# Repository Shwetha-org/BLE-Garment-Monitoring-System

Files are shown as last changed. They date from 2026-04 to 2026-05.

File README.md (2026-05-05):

# BLE Garment Monitoring System

## Overview

This project presents an end-to-end system for monitoring garment usage using a custom Bluetooth Low Energy (BLE) tag, edge processing, and a mobile application.

The system tracks garment states such as **worn**, **stored**, and **washed** by analyzing sensor data broadcast from a custom BLE-enabled garment tag.

---
## Custom BLE Garment Tag

<p align="center">
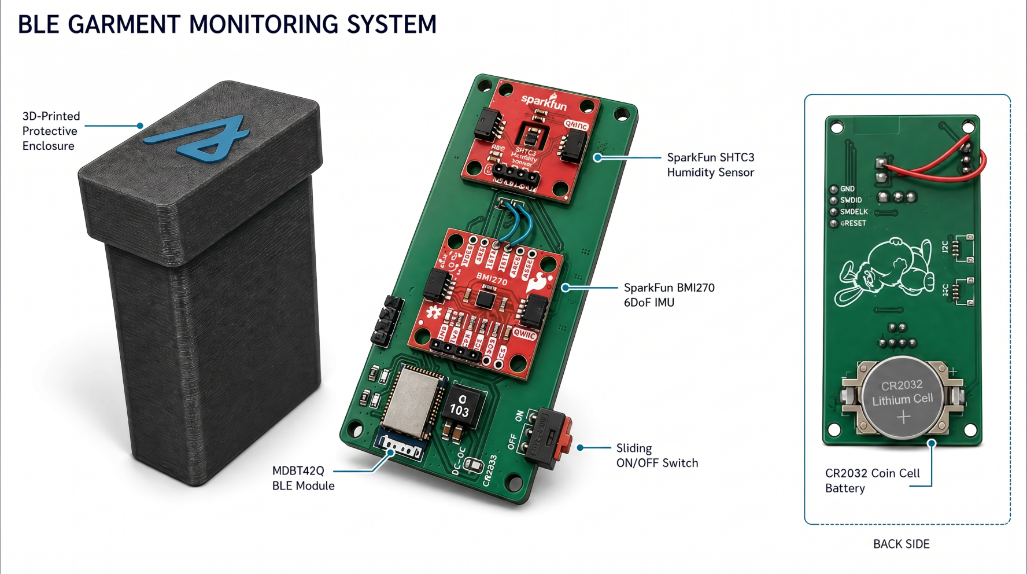
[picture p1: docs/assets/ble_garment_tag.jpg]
  
</p>

<p align="center">
  Custom BLE garment tag with integrated motion (BMI270) and humidity (SHTC3) sensors, powered by a CR2032 coin cell.
</p>

---

## System Architecture

The system consists of four main components:

### 1. Hardware (`hardware/garment_tag/`)

* Custom PCB design (KiCad)
* BLE module (nRF52832 – Raytac MDBT42Q)
* Sensors:

  * BMI270 (motion / acceleration)
  * SHTC3 (humidity and temperature)
* Assembly and manufacturing files

---

### 2. Firmware (`firmware/garment_tag/`)

* Zephyr-based firmware for the BLE tag
* Reads sensor data and encodes it into BLE advertisement payloads
* Broadcasts data continuously

---

### 3. Edge Node (`edge/`)

* Runs on Raspberry Pi
* Scans BLE advertisements using Python and Bleak
* Processes data using filtering and aggregation
* Classifies garment states (worn / stored / washed)
* Stores data in SQLite database
* Exposes REST API (`/summary`) using Flask

---

### 4. Android Application (`android_app/garment_tracker_app/`)

* Built with Kotlin and Jetpack Compose
* Connects to edge node API
* Displays:

  * Current garment state
  * Wear count
  * Wash count
* Includes privacy controls and live updates

---

## Data Flow

1. Sensors on the BLE tag collect motion, humidity, and temperature
2. Firmware encodes data into BLE advertisements
3. Raspberry Pi scans and processes the data
4. Classification pipeline determines garment state
5. Results are stored locally and exposed via API
6. Android app fetches and displays usage summaries

---

## BLE Payload Structure

The edge node expects manufacturer-specific data in the following format:

* Byte 0 → motion (0 or 1)
* Byte 1 → humidity (%)
* Byte 2 → temperature offset (temp + 40)

Manufacturer ID: `1027`

---

## Getting Started

### 1. Hardware

* Assemble the custom BLE tag
* Flash firmware onto the nRF52832

### 2. Edge Node

```bash
cd edge
pip install -r requirements.txt
python pipeline_final.py
```

### 3. Android App

* Open `android_app/garment_tracker_app/` in Android Studio
* Update Raspberry Pi IP in the code
* Run the application

---

## Requirements

* Raspberry Pi with Bluetooth
* Custom BLE garment tag
* Android device
* Python 3.x

---

## Notes

* The system operates on a local network
* The Android app requires the Raspberry Pi API to be running
* BLE payload structure must match firmware and edge logic

---

## Documentation

Detailed documentation is available in:

* `docs/architecture.md` – system design and component overview  
* `docs/setup_guide.md` – installation and setup instructions  
* `docs/User_Manual.pdf` – how to use the system (end-user guide)

---

## Project Scope

This project focuses on:

* Edge-based processing (no cloud dependency)
* Privacy-preserving garment tracking
* Lightweight BLE-based sensing

---

## License

This project is developed for academic purposes.

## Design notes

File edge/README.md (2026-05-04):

# Edge Node (Raspberry Pi)

## Overview

This component runs on the Raspberry Pi and is the core of the system.
It performs BLE scanning, signal processing, garment state classification, local data storage, and exposes a REST API for the Android application.

---

## Responsibilities

The edge node is responsible for:

* Scanning BLE advertisements from the garment tag
* Extracting sensor data (motion, humidity, temperature, gyro, RSSI)
* Applying filtering and aggregation using sliding windows
* Detecting garment states:

  * stored
  * worn
  * washed
* Storing processed data in a local SQLite database
* Exposing the latest state via a Flask API (`/summary`)

---

## Files

- `pipeline_final.py`  
  Main system used on the Raspberry Pi.  
  It scans BLE advertisements, processes sensor data, performs garment state classification, stores results in a SQLite database, and exposes a REST API.

- `scan_dk_beacon.py`  
  Debug script used with the nRF52 DK beacon.  
  It scans BLE advertisements, filters manufacturer-specific data from Nordic Semiconductor devices, and prints device ID, status, and RSSI to verify correct beacon transmission.

- `requirements.txt`  
  Dependency file for the edge node.  
  It lists the Python libraries required to run the BLE scanner, processing pipeline, and API server.

- `data/`  
  Runtime directory used by the edge node.  
  It stores the SQLite database (`garment_data.db`) that is automatically created and updated during system execution.

---

## Requirements

* Python 3.9+
* Raspberry Pi with Bluetooth enabled
* Linux environment (tested on Raspberry Pi OS)

---

## Installation

Install dependencies:

```bash
pip install -r requirements.txt
```

---

## Running the System

IMPORTANT: You must run the script from inside the `edge/` folder.

```bash
cd edge
python pipeline_final.py
```

---

## Output

### 1. SQLite Database

The system creates a database at:

```
edge/data/garment_data.db
```

This file is generated automatically at runtime and is not included in the repository.

---

### 2. Console Logs

Example output:

```
in-room | moving | state=worn | wears=2 | washes=1 | gyro_mag=4200.0 | rssi=-65 | rssi_stable=True | wash_candidate=False | wash_score=0.20
```

---

### 3. API Endpoint

The Flask server runs on:

```
http://<raspberry-pi-ip>:5000/summary
```

Example response:

```json
{
  "device_id": "0x0403",
  "state": "worn",
  "room_state": "in-room",
  "movement_state": "moving",
  "wears": 2,
  "washes": 1,
  "humidity": 45.2,
  "gyro_mag": 4100,
  "rssi": -65,
  "rssi_stable": true,
  "wash_score": 0.2
}
```

---

## State Detection Logic (Summary)

The system uses lightweight edge processing:

* Movement detection:
  Based on averaged motion values

* Room detection:
  Based on RSSI threshold

* Wash detection:
  Based on:

  * high gyro magnitude
  * stable RSSI
  * rolling wash score

* Wear detection:
  Based on sustained movement over a time window

---

## Important Notes

* The database path is relative to the current working directory
  → Always run the script from `edge/`

* The database file is created automatically
  → Do not manually add it to the repository

* BLE data is filtered to remove invalid samples before processing

---

## Debugging

To test BLE reception only:

```bash
python scan_dk_beacon.py
```

This prints raw beacon RSSI and ID values.

---

## Limitations

* Designed for a single garment device (`device_id = 0x0403`)
* Uses simple threshold-based classification
* Not optimized for multi-device environments

---

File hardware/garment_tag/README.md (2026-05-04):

# Garment Tag Hardware

## Overview

This folder contains the hardware design files for the custom BLE garment tag used in the garment monitoring system.

The garment tag is a custom-built embedded device that integrates a BLE module and sensors on a single PCB. It continuously broadcasts sensor data via BLE advertisements, which are received and processed by the Raspberry Pi edge node.

---

## Folder Structure

* `kicad/`
  Contains the KiCad schematic and PCB design files.

* `assembly/`
  Contains reference images of the assembled PCB.

* `manufacturing/`
  Contains Gerber files, drill files, and BOM used for PCB fabrication.

---

## Main Hardware Components

* Raytac MDBT42Q (nRF52832 BLE module used for BLE advertising)
* IMU sensor (used for motion and gyroscope data)
* Humidity sensor
* Coin cell battery (power supply)
* Custom PCB integrating all components into a wearable garment tag

The custom PCB integrates the BLE module and sensors into a single wearable device that continuously broadcasts environmental and motion data via BLE advertisements.

---

## KiCad Design Files

The PCB and schematic can be opened using KiCad:

```text
hardware/garment_tag/kicad/
```

Key files:

```text
ble beacon.kicad_pcb
ble beacon.kicad_sch
ble beacon.kicad_pro
```

---

## Manufacturing Files

Manufacturing files are located in:

```text
hardware/garment_tag/manufacturing/
```

These include:

* Copper layers
* Solder mask layers
* Silkscreen layers
* Drill files
* BOM (bill of materials) CSV

These files can be directly used for PCB fabrication.

---

## Assembly Reference

Assembly images are located in:

```text
hardware/garment_tag/assembly/
```

These show:

* Front of PCB
* Back of PCB
* Close-up component placement

They can be used as reference when assembling the board.

---

## Reproduction Steps

1. Open the KiCad project from `kicad/`.
2. Review the schematic and PCB layout.
3. Use the files in `manufacturing/` to fabricate the PCB.
4. Use the BOM to source components.
5. Assemble the PCB using the reference images in `assembly/`.
6. Flash firmware onto the BLE module using the nRF52 DK via SWD.
7. Power the board using a coin cell battery.
8. Verify that the device broadcasts BLE advertisement data.

---

## Notes

* The nRF52 DK is used only as a development and flashing tool.
* The custom garment tag PCB is the actual BLE device used in the system.
* The BLE advertisements from this device are processed by the edge node (`pipeline_final.py`).

---

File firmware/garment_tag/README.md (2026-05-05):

# BLE Tag Firmware

## Overview

This folder contains the firmware for the custom BLE garment tag.

The firmware runs on the nRF52832-based custom PCB and broadcasts sensor data using BLE manufacturer-specific advertisements. The Raspberry Pi edge node reads these advertisements and uses the values for garment state detection.

---

## Main Firmware File

src/customPCB_firmware.c

---

## Platform

- Zephyr RTOS  
- nRF52832 (Raytac MDBT42Q BLE module)  
- nRF52 DK used for flashing/debugging via SWD  

---

## Sensors Used

- BMI270 (IMU / accelerometer)  
- SHTC3 (humidity and temperature sensor)  

---

## Functionality

The firmware:

- initializes I2C communication  
- reads acceleration data from the BMI270  
- estimates motion based on acceleration changes  
- reads humidity and temperature from the SHTC3  
- encodes the sensor values into a BLE advertisement payload  
- broadcasts the payload periodically  

---

## BLE Advertisement Payload

The firmware encodes sensor data into manufacturer-specific data.

Expected structure:

- Byte 0 → motion flag (0 or 1)  
- Byte 1 → humidity (%)  
- Byte 2 → temperature offset (temp + 40)  

The edge node parses this payload using the same byte positions.

Manufacturer ID:

1027

---

## Flashing

1. Connect the custom PCB to the nRF52 DK using SWD  
2. Build the firmware using Zephyr  
3. Flash the firmware onto the BLE module  
4. Power the board using a coin cell battery  
5. Verify BLE advertisements using the edge node or debug scripts  

---

## Notes

- The firmware broadcasts BLE advertisements continuously  
- The payload format must match what is expected in `pipeline_final.py`  
- Incorrect payload structure will break state detection  
- The device may advertise under a custom name (e.g. MyBeacon)

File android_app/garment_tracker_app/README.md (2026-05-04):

# Android Application

## Overview

This Android application is the mobile user interface for the BLE Garment Monitoring System.

The app is built using Kotlin and Jetpack Compose. It connects to the Raspberry Pi edge node through a REST API and displays the latest garment usage summary.

---

## Main File

The main application logic is implemented in:

app/src/main/java/com/example/garmentlifecycletrackingapp/MainActivity.kt

This file contains:

- Jetpack Compose UI  
- Retrofit API connection  
- garment state display  
- wear and wash counters  
- connection status indicator  
- privacy settings dialog  

---

## Functionality

The app displays:

- current garment state  
- wear count  
- wash count  
- connection status  
- privacy settings  

The UI refreshes automatically every 2 seconds while data collection is enabled.

---

## API Connection

The app connects to the Raspberry Pi Flask API:

http://<raspberry-pi-ip>:5000/summary

In `MainActivity.kt`, the current base URL is set here:

.baseUrl("http://172.20.10.12:5000/")

When running the system on a different network, replace this IP address with the Raspberry Pi IP address.

---

## Expected API Response

The app expects a JSON response in this format:

{
  "device_id": "0x0403",
  "state": "worn",
  "wears": 2,
  "washes": 1
}

Only these fields are currently used by the Android app:

- device_id  
- state  
- wears  
- washes  

---

## Technologies Used

- Kotlin  
- Jetpack Compose  
- Material 3  
- Retrofit  
- Gson converter  
- SharedPreferences  

---

## How to Run

1. Open android_app/GarmentLifecycleTrackingApp/ in Android Studio  
2. Make sure the Raspberry Pi edge node is running  
3. Update the API base URL in MainActivity.kt  
4. Build and run the app on an Android device or emulator  

---

## Notes

- The Raspberry Pi and Android device must be on the same local network  
- The Flask API must be running before the app can display live data  
- If the app cannot connect to the API, it shows an offline/error state  
- Privacy settings are stored locally using SharedPreferences

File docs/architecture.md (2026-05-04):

# System Architecture

## Overview

The BLE Garment Monitoring System is an IoT-based system that monitors garment usage using a custom BLE garment tag, a Raspberry Pi edge node, local storage, and an Android application.

The system detects basic garment states:

* stored
* worn
* washed

---

## High-Level Architecture

```text
[Custom BLE Garment Tag]
          |
          | BLE advertisements
          v
[Raspberry Pi Edge Node]
          |
          | processing + classification
          v
[SQLite Database + Flask API]
          |
          | HTTP GET /summary
          v
[Android App]
```

---

## Components

### 1. Custom BLE Garment Tag

The garment tag is a custom PCB attached to a garment. It includes:

* Raytac MDBT42Q (nRF52832 BLE module)
* IMU sensor (motion + gyroscope)
* humidity sensor
* coin cell battery

The tag broadcasts sensor data using BLE advertisements.

Hardware files:

```text
hardware/garment_tag/
```

---

### 2. Raspberry Pi Edge Node

The Raspberry Pi acts as the edge-processing unit.

It is responsible for:

* scanning BLE advertisements
* extracting sensor data
* applying filtering and aggregation
* classifying garment state
* storing readings in SQLite
* exposing a REST API

Edge software:

```text
edge/
```

---

### 3. Local SQLite Database

The SQLite database stores processed BLE readings locally.

It is created at runtime and not included in the repository.

Expected location:

```text
edge/data/garment_data.db
```

---

### 4. Flask API

The edge node exposes:

```text
GET /summary
```

This endpoint returns the latest garment state and summary data.

---

### 5. Android Application

The Android app connects to the Raspberry Pi and displays garment state and usage.

API endpoint:

```text
http://<raspberry-pi-ip>:5000/summary
```

---

## Data Flow

1. The garment tag broadcasts sensor data via BLE.
2. The Raspberry Pi scans BLE advertisements.
3. Data is validated and filtered.
4. RSSI, motion, humidity, temperature, and gyro values are processed.
5. The system classifies the garment as stored, worn, or washed.
6. The result is stored in SQLite.
7. The latest summary is exposed via the Flask API.
8. The Android app fetches and displays the data.

---

## Design Decisions

### Edge Processing

Processing is performed locally on the Raspberry Pi.

Reasons:

* reduces data transmission
* keeps raw data local
* supports privacy
* enables offline operation

---

### SQLite Storage

SQLite is used because it is lightweight and suitable for local storage on the Raspberry Pi.

---

### Flask API

Flask provides a simple REST interface for communication with the Android application.

---

### BLE Advertisements

BLE advertisements are used instead of connections to allow low-power broadcasting without maintaining a connection.

---

## State Detection Summary

The system uses threshold-based logic and sliding windows:

* RSSI threshold → in-room vs out-of-room
* motion window → movement detection
* gyro magnitude → wash detection
* RSSI stability → distinguishes washing from movement
* wash score → confirms washing over time

---

## Current Limitations

* Supports a single garment tag
* Uses threshold-based classification (not ML-based)
* Requires tuning for different environments
* Database is local to the Raspberry Pi

---

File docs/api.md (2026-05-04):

# API

## Overview

The edge node exposes a REST API over HTTP.
The Android application uses this API to retrieve the latest garment state.

Base URL:

```text
http://<raspberry-pi-ip>:5000
```

---

## Endpoint

### GET /summary

Returns the latest processed garment data.

---

## Request

```http
GET /summary HTTP/1.1
Host: <raspberry-pi-ip>:5000
```

No parameters required.

---

## Response

```json
{
  "device_id": "0x0403",
  "state": "stored",
  "room_state": "in-room",
  "movement_state": "stationary",
  "wears": 0,
  "washes": 0,
  "humidity": 0,
  "gyro_mag": 0,
  "rssi": -65,
  "rssi_stable": true,
  "wash_score": 0
}
```

---

## Field Descriptions

* `device_id`
  Identifier of the BLE garment tag.

* `state`
  Current garment state: `stored`, `worn`, or `washed`.

* `room_state`
  Indicates whether the garment is detected as in-room or out-of-room based on RSSI.

* `movement_state`
  Indicates whether movement is detected (`moving` or `stationary`).

* `wears`
  Number of detected wear sessions.

* `washes`
  Number of detected wash events.

* `humidity`
  Averaged humidity value from sensor readings.

* `gyro_mag`
  Magnitude of gyroscope data used for motion analysis.

* `rssi`
  Received Signal Strength Indicator from BLE advertisement.

* `rssi_stable`
  Boolean indicating stability of RSSI values.

* `wash_score`
  Rolling score used to confirm wash detection.

---

## Usage Notes

* The API always returns the latest processed state.
* No authentication is required.
* The endpoint is intended for local network use.

---

## Error Handling

If the edge node is not running, the endpoint will not respond.

Ensure:

* `pipeline_final.py` is running
* Raspberry Pi is connected to the network
* correct IP address is used

---

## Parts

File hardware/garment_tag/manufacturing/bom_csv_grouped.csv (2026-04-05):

Reference | Qty | Value | DNP | Exclude from BOM | Exclude from Board | Footprint | Datasheet
C1,C2 | 2 | 10uF |  |  |  | Capacitor_SMD:C_0805_2012Metric
C3 | 1 | 1uF |  |  |  | Capacitor_SMD:C_0805_2012Metric
D1,D2 | 2 | LED |  |  |  | LED_SMD:LED_0603_1608Metric
J1 | 1 | Conn_01x03_Socket |  |  |  | Connector_PinHeader_2.54mm:PinHeader_1x03_P2.54mm_Vertical
J2 | 1 | bat |  |  |  | Battery:BatteryHolder_Keystone_1060_1x2032
J3,J8 | 2 | jst sh |  |  |  | Connector_JST:JST_SH_SM04B-SRSS-TB_1x04-1MP_P1.00mm_Horizontal
J4 | 1 | swd |  |  |  | Connector_PinHeader_2.54mm:PinHeader_1x04_P2.54mm_Vertical
J5,J6 | 2 | io |  |  |  | Connector_PinHeader_2.54mm:PinHeader_1x04_P2.54mm_Vertical
J7 | 1 | int |  |  |  | Connector_PinHeader_2.54mm:PinHeader_1x02_P2.54mm_Vertical
L2 | 1 | 10uH |  |  |  | Inductor_SMD:L_Coilcraft_XAL6030-XXX
R1,R2 | 2 | 2k2 |  |  |  | Resistor_SMD:R_0805_2012Metric
U1 | 1 | MDBT42Q-512K |  |  |  | RF_Module:Raytac_MDBT42Q | https://www.raytac.com/download/index.php?index_id=27

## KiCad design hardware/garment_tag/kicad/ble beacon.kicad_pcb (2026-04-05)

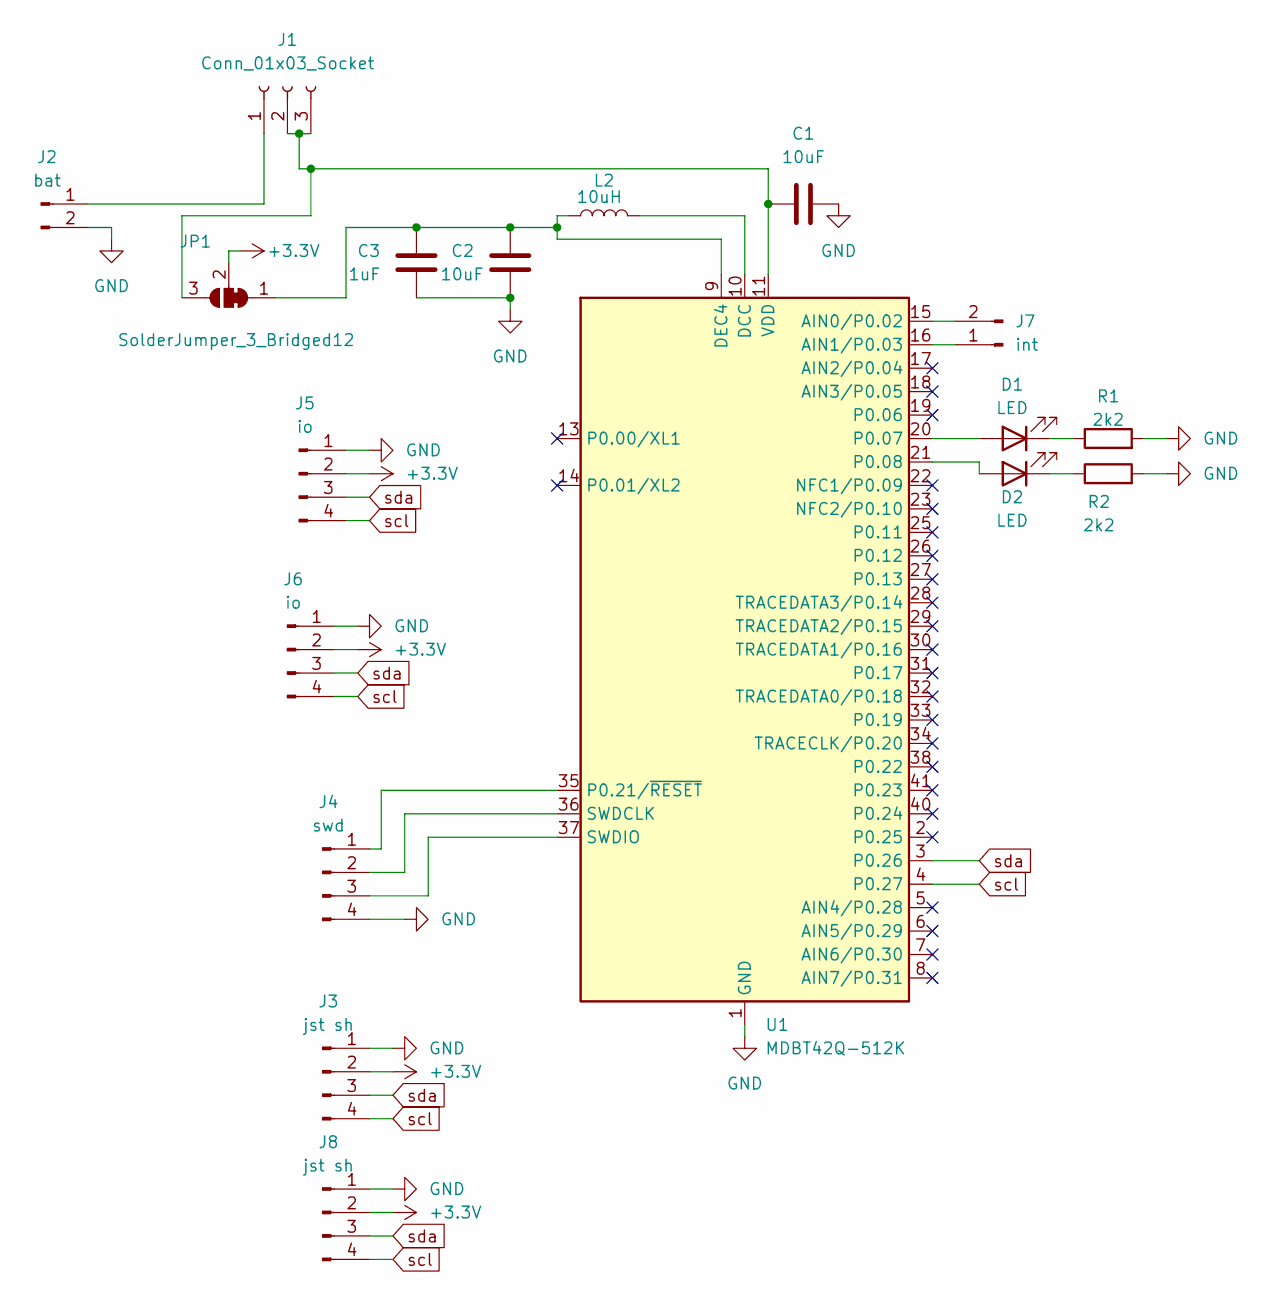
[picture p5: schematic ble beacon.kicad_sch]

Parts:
C1, C2: 10uF; C_0805_2012Metric
C3: 1uF; C_0805_2012Metric
D1, D2: LED; LED_0603_1608Metric
J1: Conn_01x03_Socket; PinHeader_1x03_P2.54mm_Vertical
J2: bat; BatteryHolder_Keystone_1060_1x2032
J3, J8: jst sh; JST_SH_SM04B-SRSS-TB_1x04-1MP_P1.00mm_Horizontal
J4: swd; PinHeader_1x04_P2.54mm_Vertical
J5, J6: io; PinHeader_1x04_P2.54mm_Vertical
J7: int; PinHeader_1x02_P2.54mm_Vertical
JP1: SolderJumper_3_Bridged12; SolderJumper-3_P1.3mm_Bridged12_RoundedPad1.0x1.5mm_NumberL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
L2: 10uH; L_Coilcraft_XAL6030-XXX
R1, R2: 2k2; R_0805_2012Metric
U1: MDBT42Q-512K; Raytac_MDBT42Q

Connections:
+3.3V: J3.2, J5.2, J6.2, J8.2, JP1.2 (C)
GND: C1.2, C2.1, C3.1, J2.2, J3.1, J3.MP, J4.4, J5.1, J6.1, J8.1, J8.MP, R1.2, R2.2, U1.1 (GND), U1.12 (GND), U1.24 (GND), U1.39 (GND)
unnamed: D1.2 (A), U1.20 (P0.07)
unnamed: D1.1 (K), R1.1
unnamed: D2.2 (A), U1.21 (P0.08)
unnamed: D2.1 (K), R2.1
unnamed: J1.1, J2.1
unnamed: C1.1, J1.2, J1.3, JP1.3 (B), U1.11 (VDD)
unnamed: J4.1, U1.35 (P0.21/~RESET)
unnamed: J4.2, U1.36 (SWDCLK)
unnamed: J4.3, U1.37 (SWDIO)
unnamed: J7.1, U1.16 (AIN1/P0.03)
unnamed: J7.2, U1.15 (AIN0/P0.02)
unnamed: C2.2, C3.2, JP1.1 (A), L2.1, U1.9 (DEC4)
unnamed: L2.2, U1.10 (DCC)
scl: J3.4, J5.4, J6.4, J8.4, U1.4 (P0.27)
sda: J3.3, J5.3, J6.3, J8.3, U1.3 (P0.26)

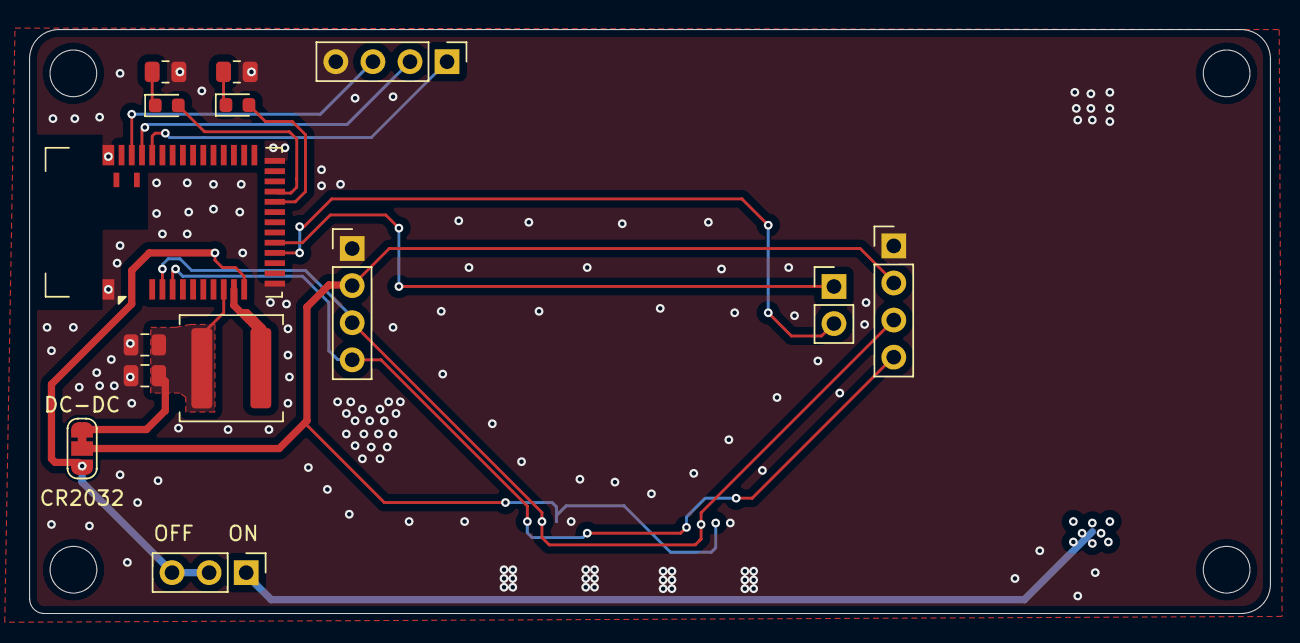
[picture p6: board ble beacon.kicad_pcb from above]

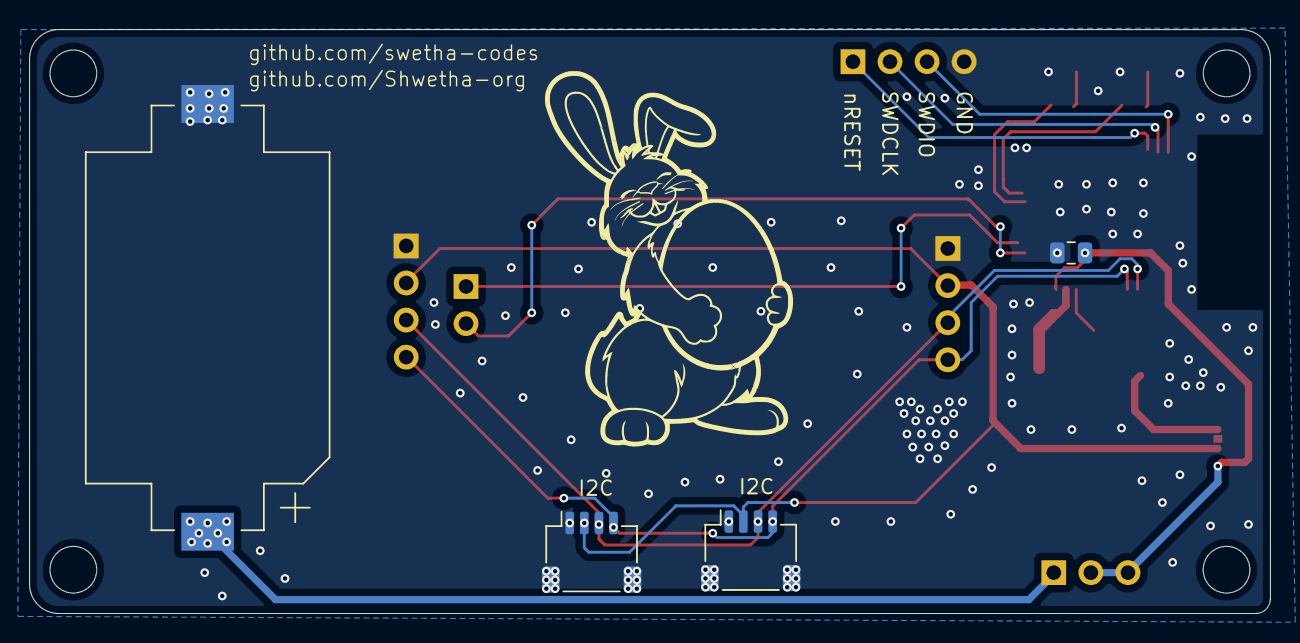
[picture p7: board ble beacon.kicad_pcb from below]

Board: 2 copper layers, 85.0 x 40.0 mm, 18 parts (4 on the bottom side), 17 nets.

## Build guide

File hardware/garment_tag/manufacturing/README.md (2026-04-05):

# BBGT BLE Garment Tag – PCB Outputs

This folder contains the manufacturing outputs for the **BLE garment tag** (BBGT) used in the circular fashion garment tracking system, revision 1.

## Files

- `ble-beacon-*.gbr` – Gerber files for all copper, mask, paste, silkscreen and edge cuts layers.  
- `ble-beacon-*.drl` – Drill files for plated and non‑plated holes.  
- `ble-beacon-job.gbrjob` – KiCad fabrication job file (optional for fab).  
- `tag_final_bom.csv` – Bill of materials for assembly.

You can zip this folder and upload it directly to any standard PCB manufacturer that supports KiCad/RS‑274X Gerbers.

## Electrical and programming

- Supply voltage: 3 V from CR2032 coin cell.  
- MCU/Module: nRF52832 BLE module.  
- Programming: 2×5 1.27 mm SWD header.

SWD header pinout (top view, notch on the left):

1. VCC (3 V)  
2. SWDIO  
3. SWCLK  
4. GND  
5. RESET

## Layout and assembly notes

- Keep‑out: Do **not** place copper, ground pour, or tall components under the RF module antenna region on any layer.  
- Place the tag away from large metal surfaces for best RF performance.  
- IMU and additional sensors are optional for basic BLE advertising functionality.

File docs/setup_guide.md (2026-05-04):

# Setup Guide

## 1. Clone the Repository

```bash
git clone https://github.com/Shwetha-org/BLE-Garment-Monitoring-System.git
cd BLE-Garment-Monitoring-System
```

---

## 2. Required Hardware

* Custom BLE garment tag
* Raspberry Pi with Bluetooth enabled
* nRF52 DK for flashing/debugging the custom tag
* Coin cell battery for the garment tag
* Android device or emulator

---

## 3. Install Edge Dependencies

```bash
cd edge
pip install -r requirements.txt
```

---

## 4. Run the Edge Node

Run from inside the `edge/` folder:

```bash
python pipeline_final.py
```

The edge node will:

* scan BLE advertisements
* classify garment state
* store readings in SQLite
* start the Flask API

---

## 5. Verify Database Creation

After running the edge node, the database is created at:

```text
edge/data/garment_data.db
```

This file is generated at runtime and is not committed to GitHub.

---

## 6. Verify API

Open this in a browser or use curl:

```text
http://<raspberry-pi-ip>:5000/summary
```

Expected output format:

```json
{
  "device_id": "0x0403",
  "state": "stored",
  "room_state": "in-room",
  "movement_state": "stationary",
  "wears": 0,
  "washes": 0,
  "humidity": 0,
  "gyro_mag": 0,
  "rssi": -65,
  "rssi_stable": true,
  "wash_score": 0
}
```

---

## 7. Optional BLE Debug Scan

To test BLE advertising separately:

```bash
python scan_dk_beacon.py
```

This script is used to verify BLE advertisement transmission and RSSI before running the full pipeline.

---

## 8. Android App Setup

1. Open `android_app/` in Android Studio.
2. Set the API base URL to:

```text
http://<raspberry-pi-ip>:5000
```

3. Build and run the app.
4. Confirm that the app displays the garment state returned by `/summary`.

---

## 9. Reproduction Checklist

A successful setup should have:

* BLE garment tag powered and advertising
* Raspberry Pi scanning BLE packets
* `pipeline_final.py` running without errors
* SQLite database created under `edge/data/`
* `/summary` API returning JSON
* Android app displaying the summary

---

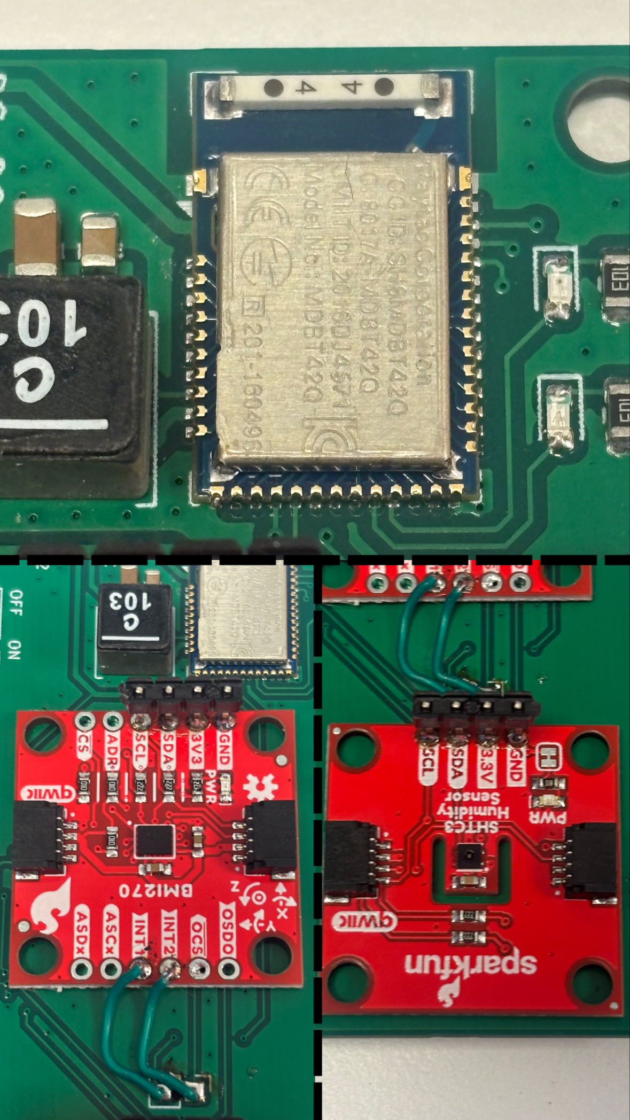
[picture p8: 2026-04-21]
hardware/garment_tag/assembly/pcb - closeups.JPG

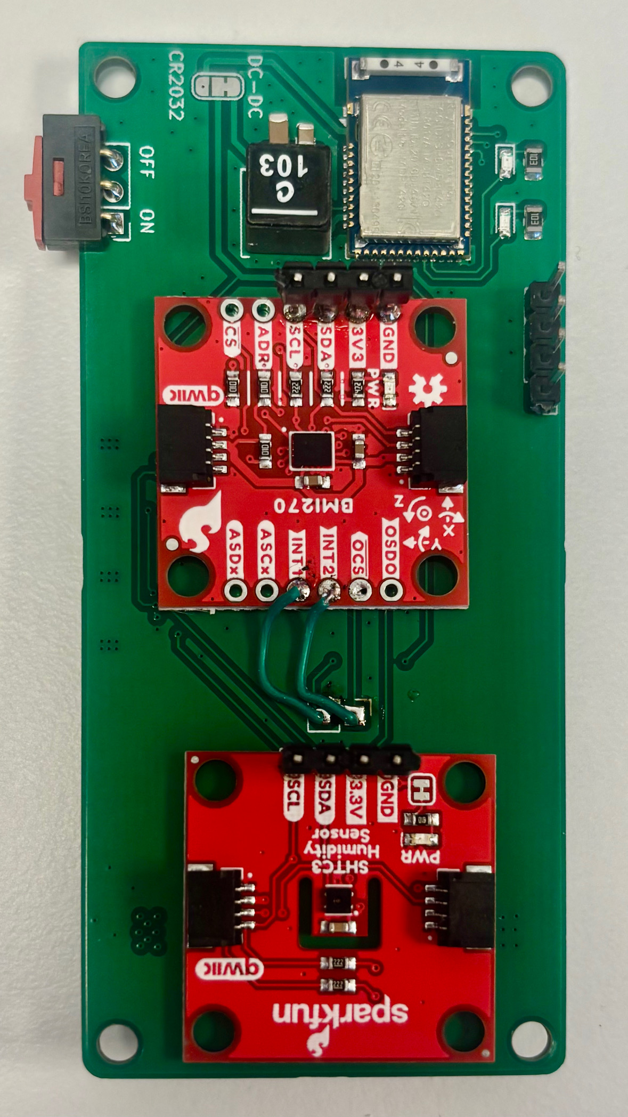
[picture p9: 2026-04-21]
hardware/garment_tag/assembly/pcb - front.jpg

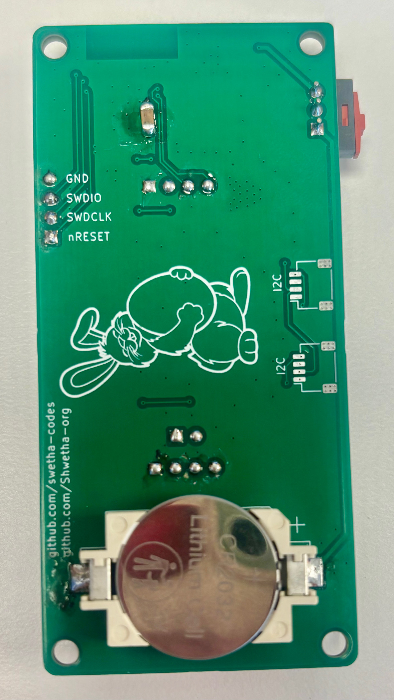
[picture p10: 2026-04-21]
hardware/garment_tag/assembly/pcb - back.jpg

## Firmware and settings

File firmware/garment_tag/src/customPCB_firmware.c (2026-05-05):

#include <zephyr/kernel.h>
#include <zephyr/device.h>
#include <zephyr/drivers/i2c.h>
#include <zephyr/bluetooth/bluetooth.h>
#include <zephyr/bluetooth/hci.h>
#include <stdlib.h>

#include "bmi2.h"
#include "bmi270.h"

#define I2C_NODE DT_NODELABEL(i2c1)
#define BMI_ADDR 0x68
#define SHTC3_ADDR 0x70

static const struct device *i2c_dev = DEVICE_DT_GET(I2C_NODE);
static struct bmi2_dev bmi;

/* 03 04 = ID, then motion, humidity, temp+40 */
uint8_t adv_payload[5] = {0x03, 0x04, 0x00, 0x00, 0x00};

static struct bt_data ad[] = {
    BT_DATA(BT_DATA_NAME_COMPLETE, "MyBeacon", 8),
    BT_DATA(BT_DATA_MANUFACTURER_DATA, adv_payload, 5),
};

int8_t user_i2c_read(uint8_t reg_addr, uint8_t *data, uint32_t len, void *intf_ptr)
{
    return i2c_burst_read(i2c_dev, BMI_ADDR, reg_addr, data, len);
}

int8_t user_i2c_write(uint8_t reg_addr, const uint8_t *data, uint32_t len, void *intf_ptr)
{
    return i2c_burst_write(i2c_dev, BMI_ADDR, reg_addr, data, len);
}

void user_delay_us(uint32_t period, void *intf_ptr)
{
    k_usleep(period);
}

static int read_shtc3(uint8_t *humidity_percent, int8_t *temp_c)
{
    uint8_t wake[2] = {0x35, 0x17};
    uint8_t measure[2] = {0x7C, 0xA2};
    uint8_t sleep_cmd[2] = {0xB0, 0x98};
    uint8_t data[6];

    i2c_write(i2c_dev, wake, 2, SHTC3_ADDR);
    k_msleep(2);

    if (i2c_write(i2c_dev, measure, 2, SHTC3_ADDR) < 0) {
        return -1;
    }

    k_msleep(20);

    if (i2c_read(i2c_dev, data, 6, SHTC3_ADDR) < 0) {
        return -1;
    }

    uint16_t raw_t = ((uint16_t)data[0] << 8) | data[1];
    uint16_t raw_h = ((uint16_t)data[3] << 8) | data[4];

    float temp = -45.0f + 175.0f * ((float)raw_t / 65535.0f);
    float hum = 100.0f * ((float)raw_h / 65535.0f);

    if (hum < 0) hum = 0;
    if (hum > 100) hum = 100;

    *humidity_percent = (uint8_t)hum;
    *temp_c = (int8_t)temp;

    i2c_write(i2c_dev, sleep_cmd, 2, SHTC3_ADDR);

    return 0;
}

int main(void)
{
    struct bmi2_sens_config config;
    struct bmi2_sens_data sensor_data;
    int32_t prev_mag = 0;

    bt_enable(NULL);

    if (!device_is_ready(i2c_dev)) {
        while (1) k_msleep(1000);
    }

    bmi.read = user_i2c_read;
    bmi.write = user_i2c_write;
    bmi.delay_us = user_delay_us;
    bmi.intf = BMI2_I2C_INTF;

    bmi270_init(&bmi);

    config.type = BMI2_ACCEL;
    config.cfg.acc.odr = BMI2_ACC_ODR_100HZ;
    config.cfg.acc.range = BMI2_ACC_RANGE_2G;
    config.cfg.acc.bwp = BMI2_ACC_NORMAL_AVG4;
    config.cfg.acc.filter_perf = BMI2_PERF_OPT_MODE;

    bmi2_set_sensor_config(&config, 1, &bmi);

    uint8_t sens_list[1] = { BMI2_ACCEL };
    bmi2_sensor_enable(sens_list, 1, &bmi);

    bt_le_adv_start(BT_LE_ADV_NCONN, ad, ARRAY_SIZE(ad), NULL, 0);

    while (1) {
        if (bmi2_get_sensor_data(&sensor_data, &bmi) == BMI2_OK) {
            int32_t ax = sensor_data.acc.x;
            int32_t ay = sensor_data.acc.y;
            int32_t az = sensor_data.acc.z;

            int32_t mag = abs(ax) + abs(ay) + abs(az);
            int32_t diff = abs(mag - prev_mag);
            prev_mag = mag;

            adv_payload[2] = (diff > 500) ? 1 : 0;
        }

        uint8_t humidity;
        int8_t temp;

        if (read_shtc3(&humidity, &temp) == 0) {
            adv_payload[3] = humidity;
            adv_payload[4] = (uint8_t)(temp + 40);
        }

        bt_le_adv_update_data(ad, ARRAY_SIZE(ad), NULL, 0);
        k_msleep(1000);
    }
}

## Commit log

2026-04-05 Initial project structure and README
    [ble beacon-B_Cu.gbr, ble beacon-B_Mask.gbr, ble beacon-B_Paste.gbr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]
2026-04-05 Organize BLE tag PCB: move manufacturing outputs to outputs/
    [ble beacon-B_Cu.gbr, ble beacon-B_Mask.gbr, ble beacon-B_Paste.gbr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]
2026-04-21 Add BLE beacon assembly photos and notes for tag PCB
2026-04-21 Replace beacon assembly HEIC photos with JPGs
    [ble beacon.kicad_sch]
2026-04-21 Update beacon assembly JPG photos
2026-05-04 Organize garment tag hardware files
    [ble beacon-B_Cu.gbr, ble beacon-B_Mask.gbr, ble beacon-B_Paste.gbr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]
